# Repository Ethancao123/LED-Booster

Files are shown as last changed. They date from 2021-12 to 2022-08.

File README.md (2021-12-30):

# LED-Booster

An LED board for FRC designed to be used with the Limelight.

The board is single layer to allow for the use aluminum base PCBs.

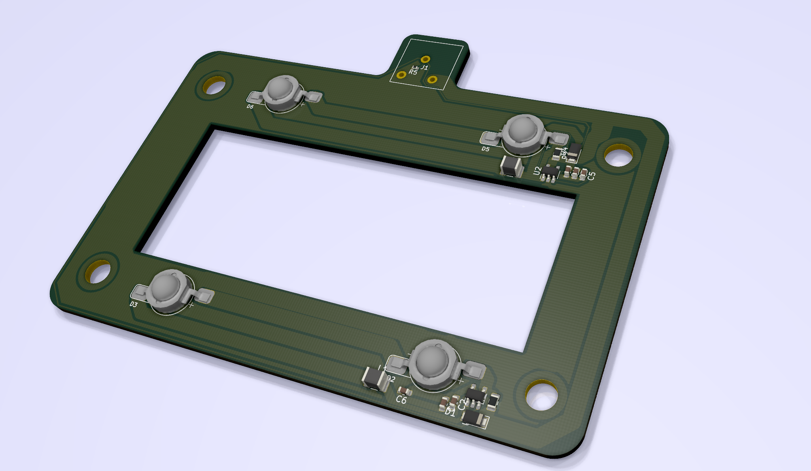
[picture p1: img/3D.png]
3D Render


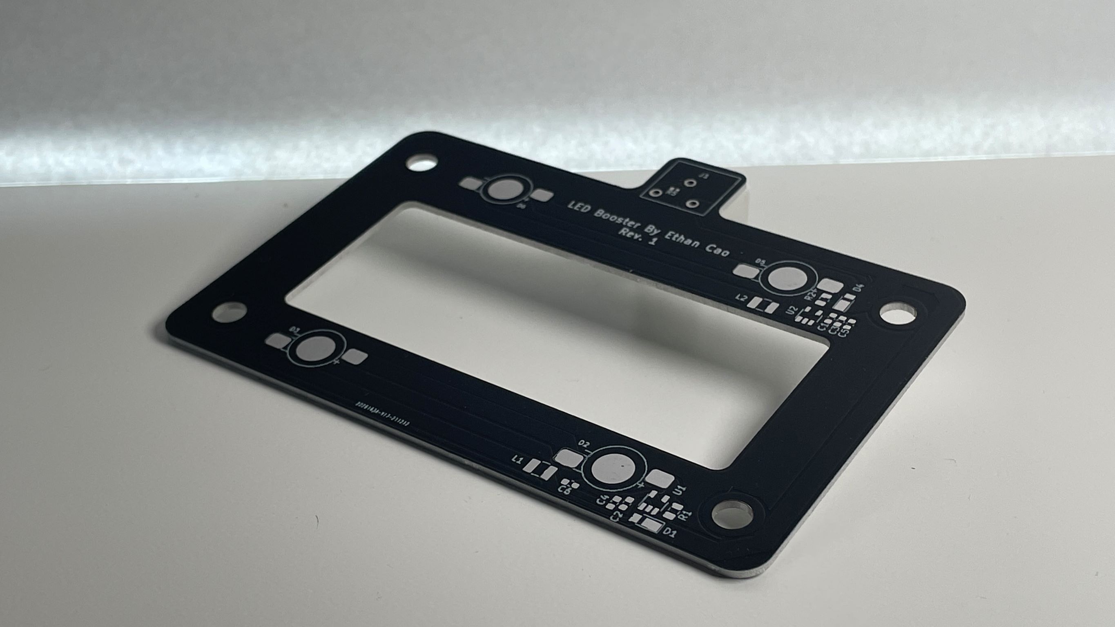
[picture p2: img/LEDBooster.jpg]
PCB


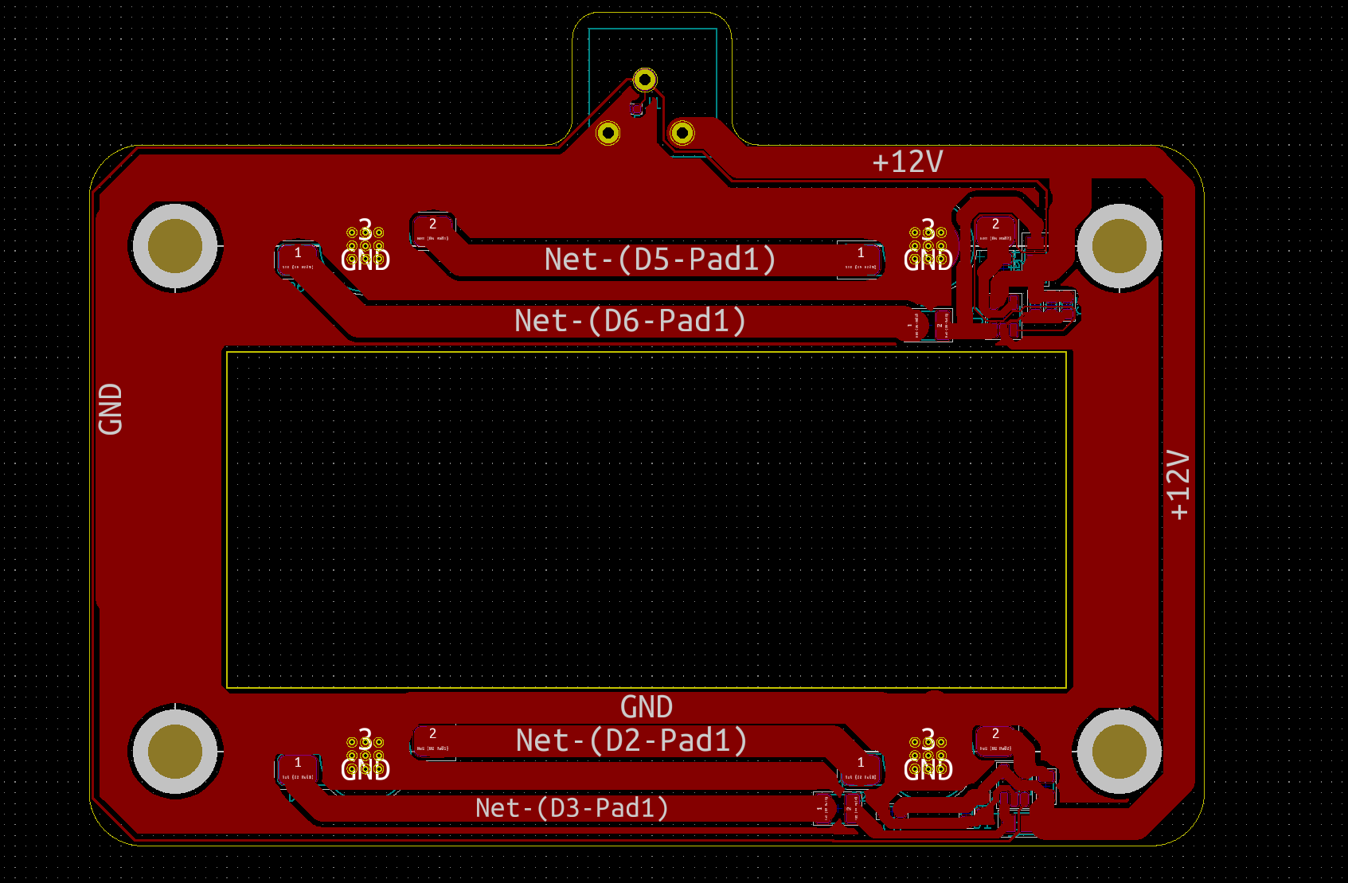
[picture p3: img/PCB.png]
Board


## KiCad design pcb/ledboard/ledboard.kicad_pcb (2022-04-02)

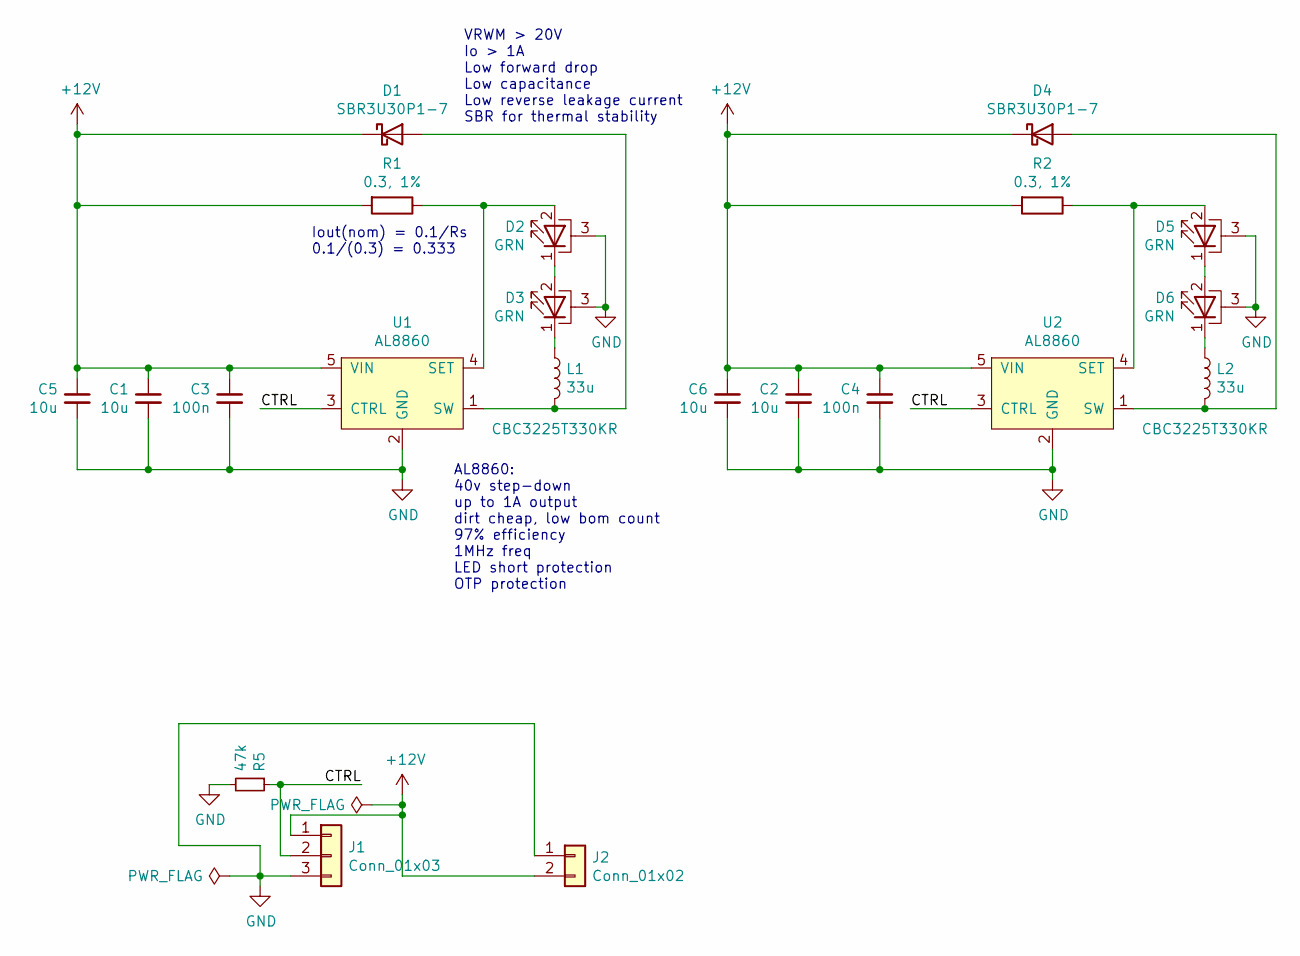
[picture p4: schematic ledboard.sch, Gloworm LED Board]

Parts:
C1, C2, C5, C6: 10u; C_0603_1608Metric; LCSC C96446
C3, C4: 100n; C_0603_1608Metric; LCSC C106256
D1, D4: SBR3U30P1-7; D_PowerDI-123; LCSC C110517
D2, D3, D5, D6: GRN; LED_1W_3W_R8
J1: Conn_01x03; WJ250B-3pin
J2: Conn_01x02; AMASS_XT30U-M_1x02_P5.0mm_Vertical
L1, L2: 33u; L_1210_3225Metric; LCSC C223226
R1, R2: 0.3, 1%; R_0805_2012Metric; LCSC C247157
R5: 47k; R_0603_1608Metric; LCSC C25563
U1, U2: AL8860; TSOT-23-5_RoundRect; LCSC C125330

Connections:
+12V: C1.1, C2.1, C3.1, C4.1, C5.1, C6.1, D1.1 (K), D4.1 (K), J1.1, J2.2, R1.2, R2.2, U1.5 (VIN), U2.5 (VIN)
/CTRL: J1.2, R5.1, U1.3 (CTRL), U2.3 (CTRL)
GND: C1.2, C2.2, C3.2, C4.2, C5.2, C6.2, D2.3 (PAD), D3.3 (PAD), D5.3 (PAD), D6.3 (PAD), J1.3, J2.1, R5.2, U1.2 (GND), U2.2 (GND)
unnamed: D1.2 (A), L1.2, U1.1 (SW)
unnamed: D2.1 (K), D3.2 (A)
unnamed: D2.2 (A), R1.1, U1.4 (SET)
unnamed: D3.1 (K), L1.1
unnamed: D4.2 (A), L2.2, U2.1 (SW)
unnamed: D5.1 (K), D6.2 (A)
unnamed: D5.2 (A), R2.1, U2.4 (SET)
unnamed: D6.1 (K), L2.1

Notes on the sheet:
Iout(nom) = 0.1/Rs 0.1/(0.3) = 0.333
VRWM > 20V Io > 1A Low forward drop Low capacitance Low reverse leakage current SBR for thermal stability
AL8860: 40v step-down up to 1A output dirt cheap, low bom count 97% efficiency 1MHz freq LED short protection OTP protection

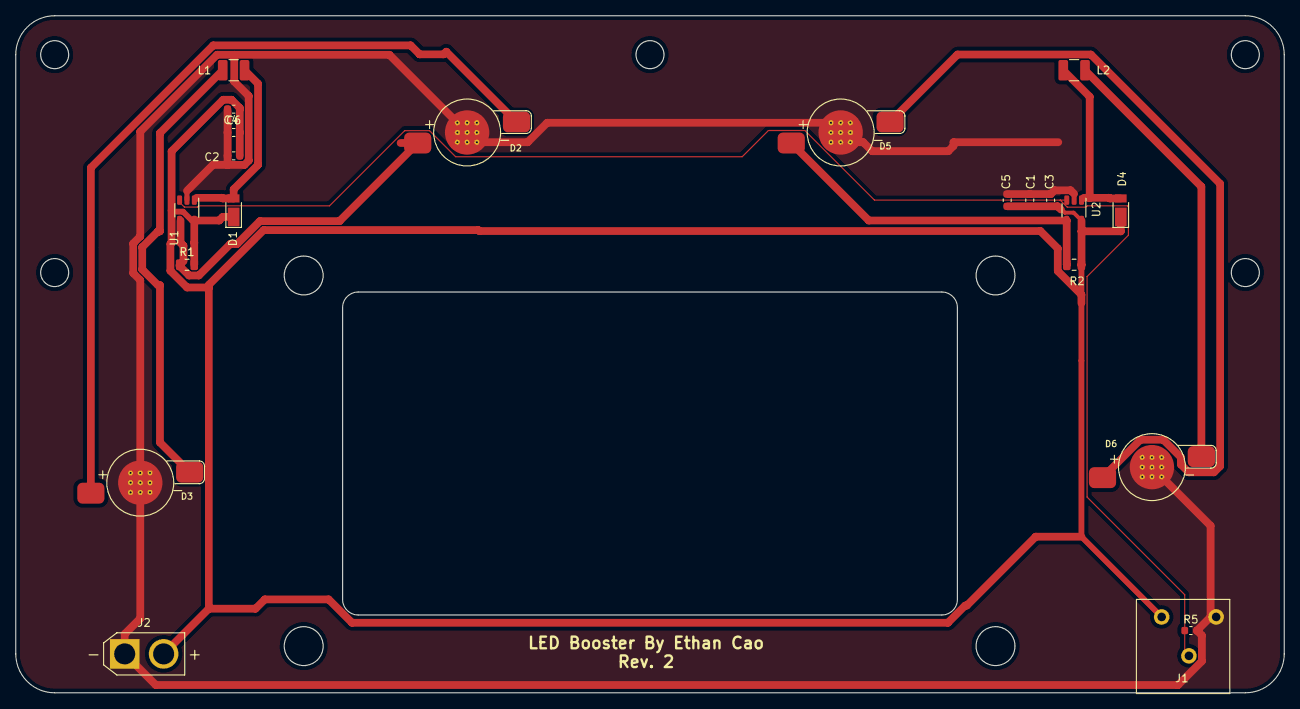
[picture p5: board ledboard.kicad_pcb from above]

Board: 2 copper layers, 163.0 x 87.0 mm, 21 parts (0 on the bottom side), 11 nets.

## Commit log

2021-12-10 Cleaned up files
    [GlowormCase.step, GlowormFrontCase.stl, GlowormRearCase.stl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]
2021-12-11 Created LED Board
    [ledboard.kicad_pcb, ledboard.sch]
2021-12-11 Finished pcb
    [ledboard.kicad_pcb, ledboard.sch]
2021-12-30 [ImgBot] Optimize images
    *Total -- 1,018.41kb -> 984.80kb (3.3%)
    /img/PCB.png -- 85.49kb -> 72.63kb (15.05%)
    /img/3D.png -- 932.92kb -> 912.17kb (2.22%)
2022-03-29 started v2
    [ledboard.kicad_pcb]
2022-03-29 [ImgBot] Optimize images
    *Total -- 410.11kb -> 356.19kb (13.15%)
    /pcb/ledboard/ledboard-brd.svg -- 46.48kb -> 37.47kb (19.39%)
    /img/LEDBooster.jpg -- 278.13kb -> 246.10kb (11.52%)
    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
2022-03-30 ledboard kinda done???
    [ledboard.kicad_pcb, ledboard.sch]

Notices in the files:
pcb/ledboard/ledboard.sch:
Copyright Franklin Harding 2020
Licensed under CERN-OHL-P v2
